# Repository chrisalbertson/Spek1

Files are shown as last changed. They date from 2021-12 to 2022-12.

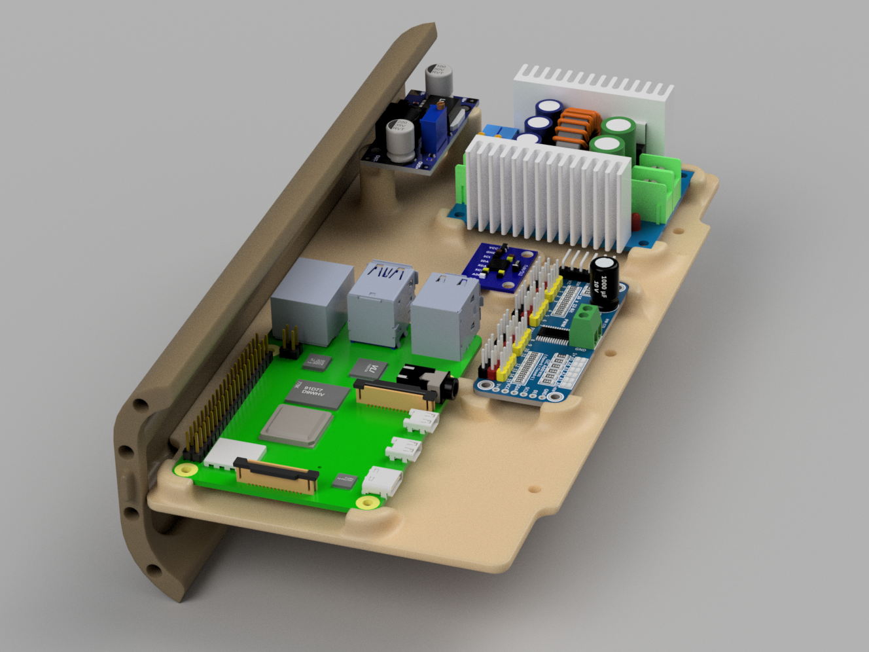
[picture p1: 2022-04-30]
Docs/trunk2 v34.png

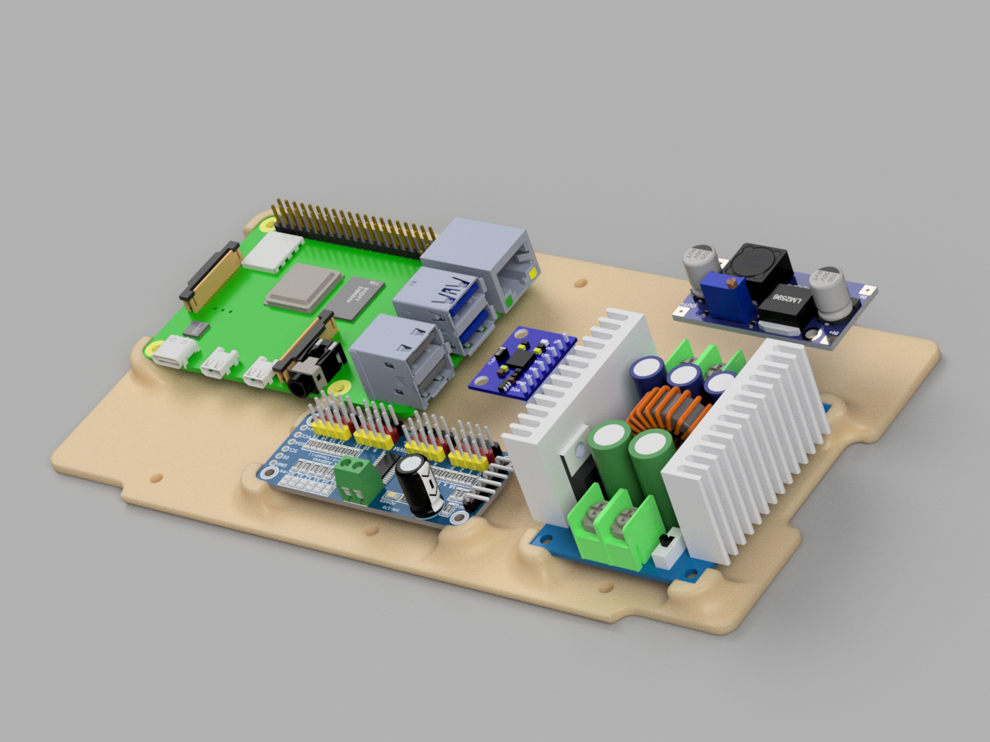
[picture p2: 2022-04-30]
Docs/trunk2 v30.png

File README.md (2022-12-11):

# Spek1

This repository holds my version of “Spot Micro” which was originated by Thingiverse user “KDY0523”. 

Why the name "Spek1"?  The work "Speck" means a small spot. and this robot is inspired by Boston Dynamic's "Spot", but this robot is much small.  It is a smaller Spot.    Then the leter "c" is removed.    The number "1" is added to imply that there coud be a series of these robots.

### Motivation

There are many Spot Micro projects on the Internet.  They are all derived from the same KDY0523 original.  I wanted a project that could incorporate some of the best ideas from other Spot Micro versions, plus some of my own ideas.  One of my main goals was to make a modifiable design.  I wanted modular and swapable parts.

The CAD files were all re-drawn, but retain the look and dimension of the original as much as possible. 

This Spot Micro uses a Raspberry Pi4 running Ubuntu Linux as the controller.  But the electronics are mounted to a tray and can be sapped out as a pre-wired unit, battery, power supplies, computer and all.

### How To Build

You can simply 3D print all the STL files and install the software on the Pi4 and you will in theory have a copy of my latest version.  Detailed instructions for doing this are in other documents in this repository.

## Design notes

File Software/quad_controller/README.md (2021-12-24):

# Quad Controller
This is what runs on the computer that is inside the robot.  

The target environment is a Raspberry Pi4 rning Ubuntu Linux.  But this
software is developed on a desktop Linux PC and runs there too in "simulation
mode" where the data that would have been sent to robot hardware is written 
to a log file.

At present this software does not do much.  I am using just one leg mounted
to a workbench to suport development.     It is still very early in the 
development process.

The goal is that the robot will move under remote control but make many of 
the decisions about hove to walk and balance by itself.   The remote
control will be either web based or via a remote X11 screen of by a
gamepad controller.

To run this type "python3 main.py"  then look at
http://localhost:2222 for a simply window.  Click on some controls and see
if anything happens.

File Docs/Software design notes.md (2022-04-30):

# Leg Motion Generator
## Inputs
* Velocity
	* angle relative to "front"
	* stride length (meters)
	* stride period (seconds)
* body pose
	* height
	* roll, pitch and yaw
* Stride Phase (normalized time)
* Preferred gait (amble, trot, ...)
## Outputs
* foot position in (x, y, z)
* foot velocity in (x', y', z')

## Implementation
### Startup
* initialize Leg object for each leg (call constructor function)
	* phase set to 0.0 (the neutral position)
* initialize body object (call constructor function)
	* set to "flat" and normal height above ground
* Start servo loop (run at maybe 20 Hz or faster)
	* find the foot contact plygon. This could be a point, line, triangle or quadrilateral
	* translate body so that center of gravity (accountng for direction gravity vector) is inside the foot-contact polygon
	* rotate body angles as much as possible to desired pose.
	* Adjust stance width or length if required to meet current stability goal.

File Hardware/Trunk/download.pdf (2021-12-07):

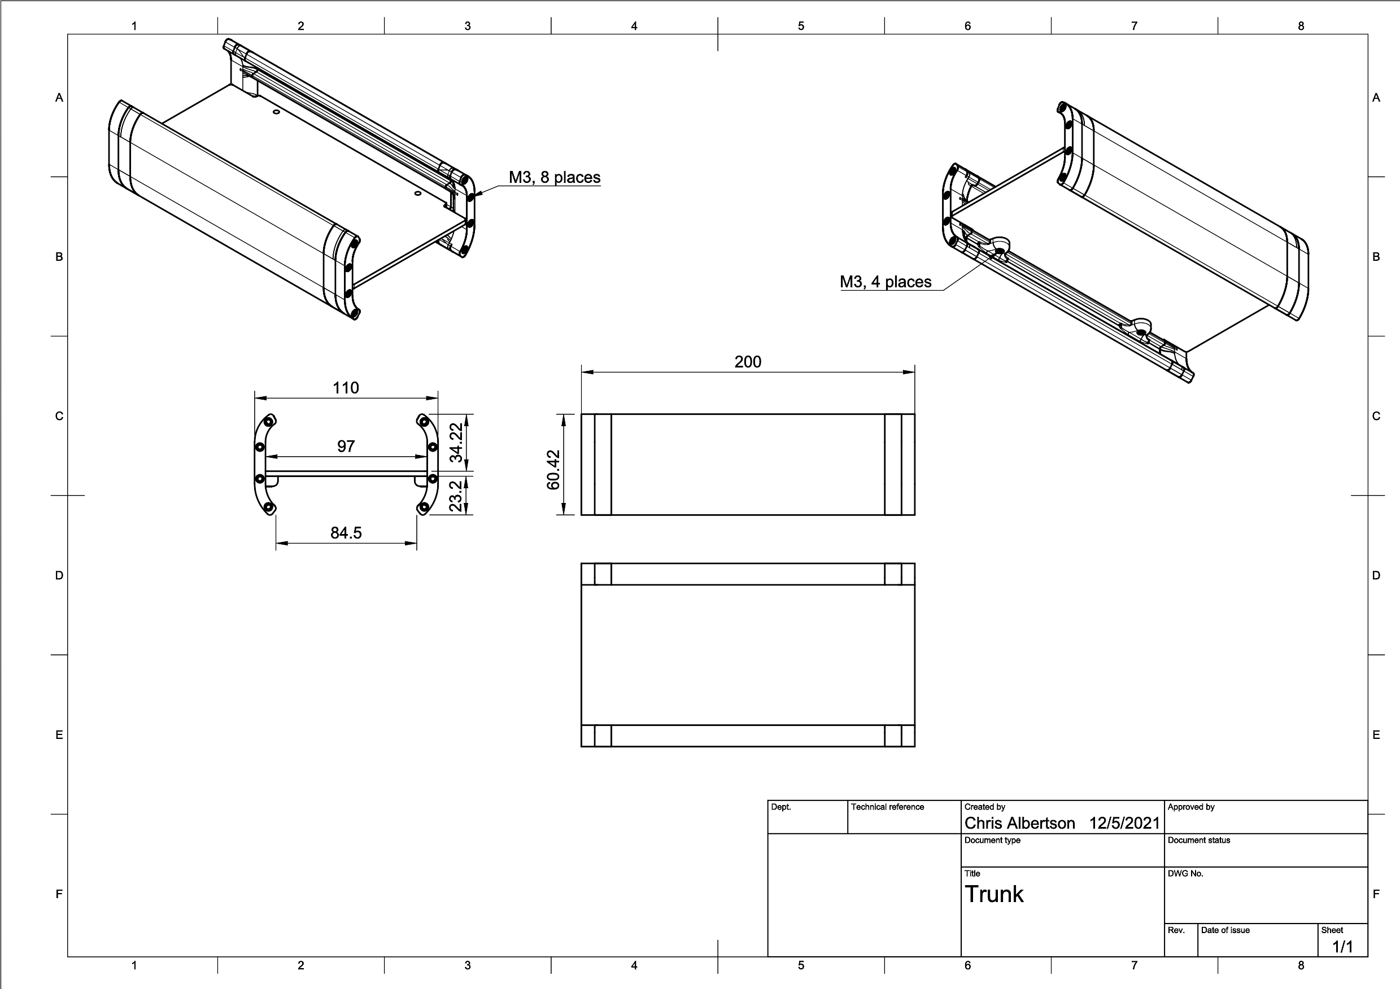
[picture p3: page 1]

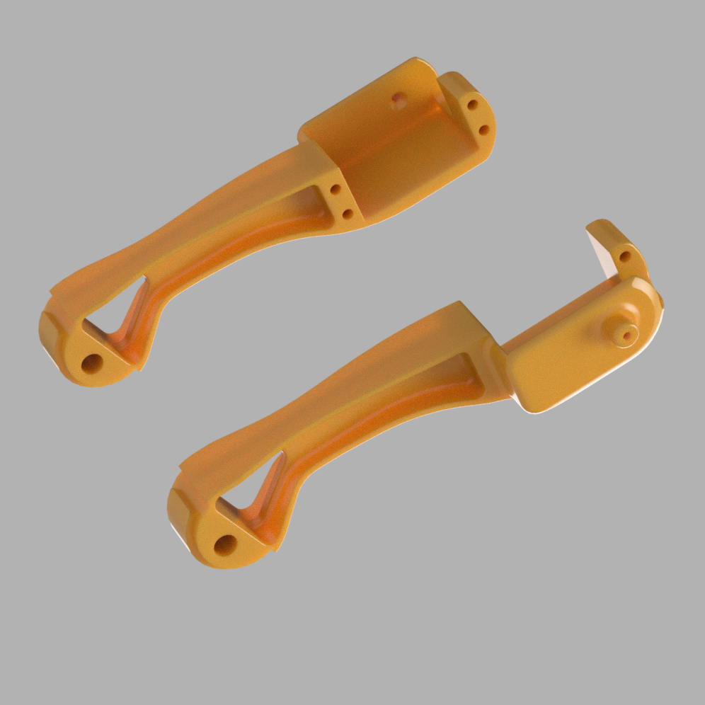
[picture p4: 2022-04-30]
Hardware/Legs/Spot MM1 Leg v29.png

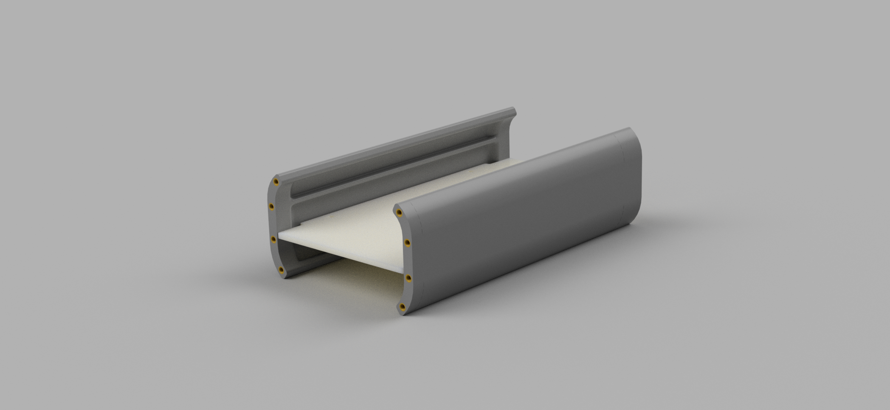
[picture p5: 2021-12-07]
Hardware/Trunk/Trunk v34.png

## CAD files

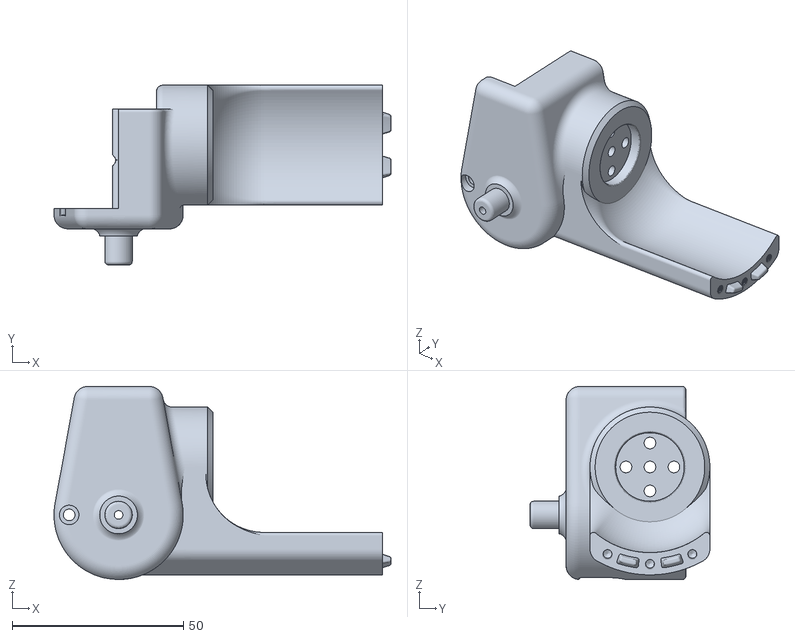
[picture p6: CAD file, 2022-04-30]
Hardware/Shoulder/ShoulderBlockMain.stl
98.4 x 52.5 x 56.4

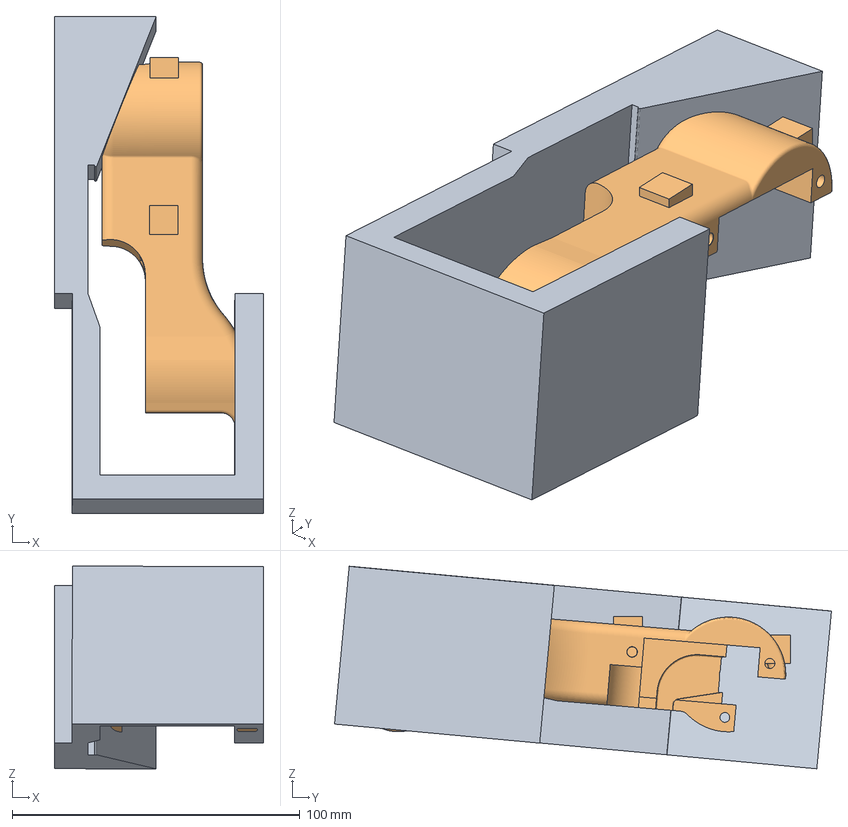
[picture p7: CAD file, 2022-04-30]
Hardware/Legs/upper_leg_mk2/AA6_upper_leg_main.3mf
72.7 x 172.6 x 70.4 mm
Print_Tool.stl
upper_leg_main.stl

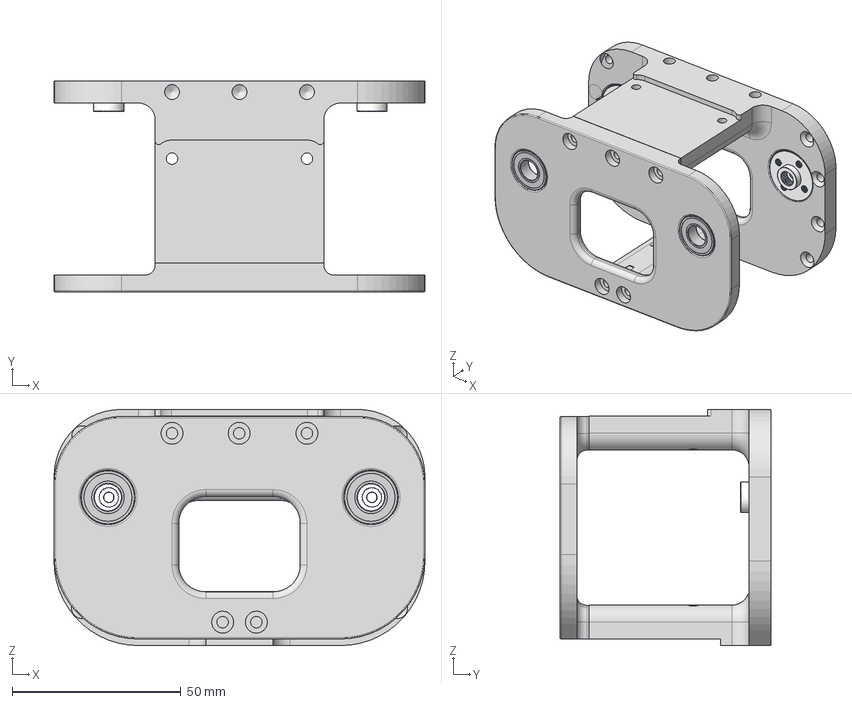
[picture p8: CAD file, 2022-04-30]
Hardware/Shoulder/Spot MM1 Shoulder Assembly v46.step
110.0 x 62.5 x 70.0 mm
Inner_Plate
Outer_Plate
_F688AZZ Outer Ring
_F688AZZ Inner Ring
_F688AZZ Shield1
_F688AZZ Ball x 12
_F688AZZ Shield2
_F688AZZ Outer Ring (1)
_F688AZZ Inner Ring (1)
_F688AZZ Shield1 (1)
_F688AZZ Ball (1) x 12
_F688AZZ Shield2 (1)

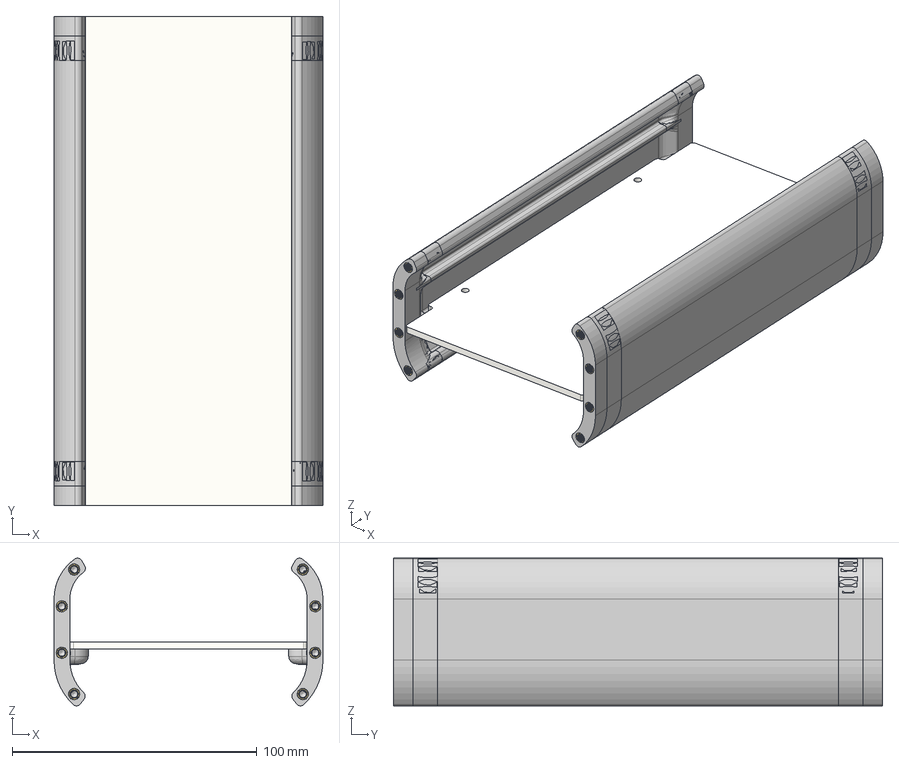
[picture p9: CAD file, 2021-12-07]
Hardware/Trunk/Trunk Assembly.step
110.0 x 200.0 x 60.4 mm
side plate, plastic only, LR x 2
F1-B-M3-Heatfit v1 (1) x 20
Tray

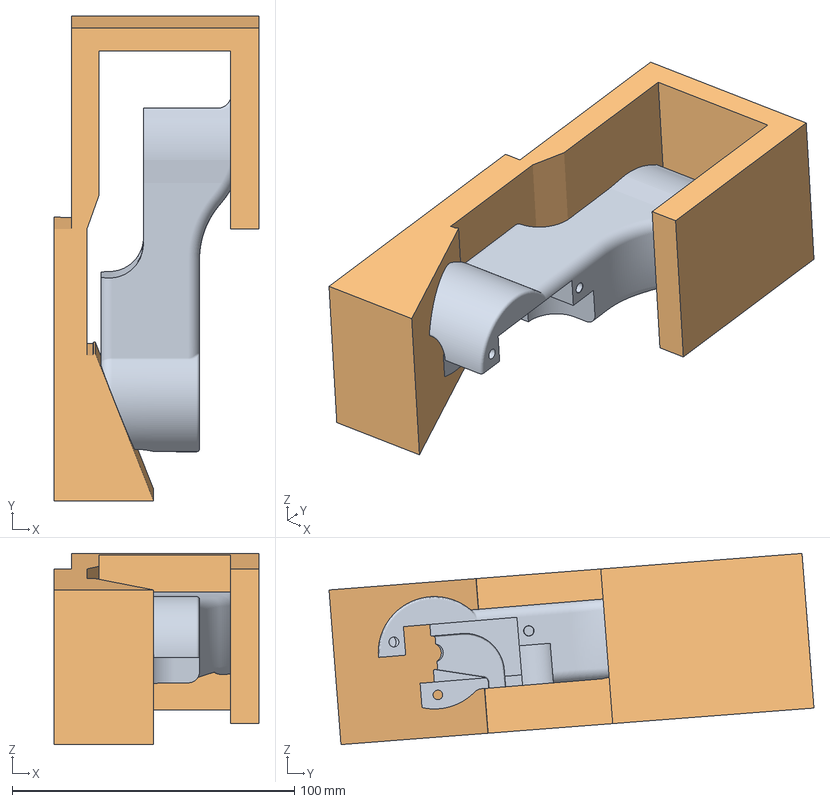
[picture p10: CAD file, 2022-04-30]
Hardware/Legs/upper_leg_mk2/AA6_upper_leg_main(Mirror).3mf
72.7 x 172.0 x 67.8 mm
upper_leg_main(Mirror).stl
Print_Tool.stl

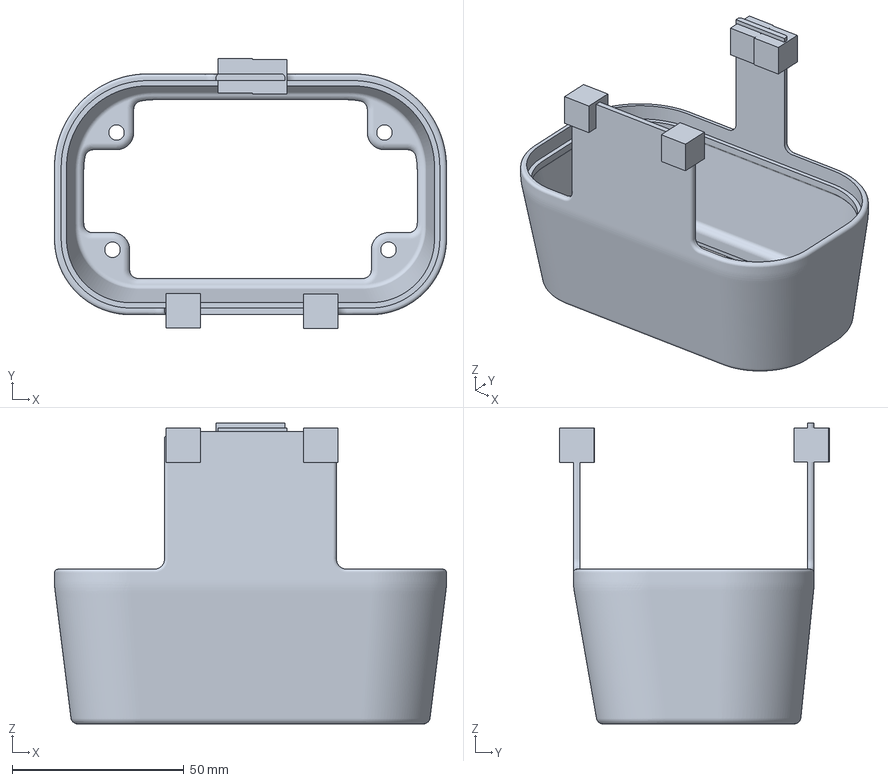
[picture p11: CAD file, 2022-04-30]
Hardware/covers/AA6_cover_tail.3mf
114.0 x 78.5 x 87.5 mm

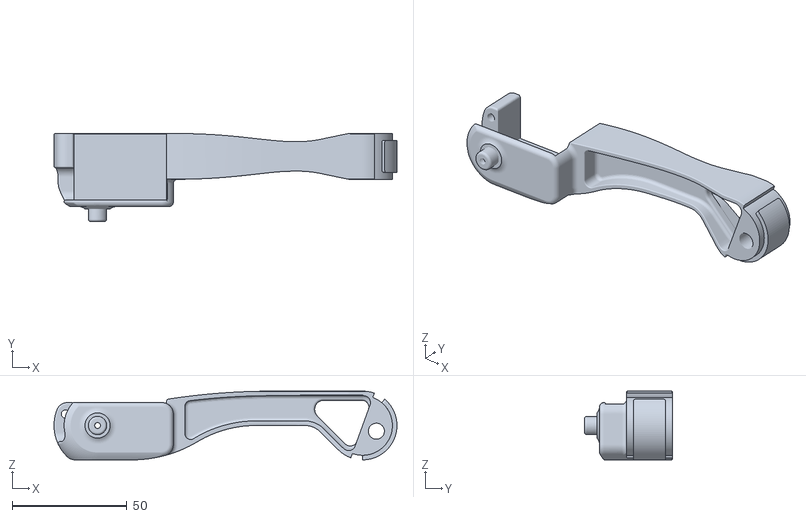
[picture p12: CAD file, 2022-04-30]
Hardware/Legs/LowerLeg_Mirror.stl
149.6 x 38.4 x 30.0

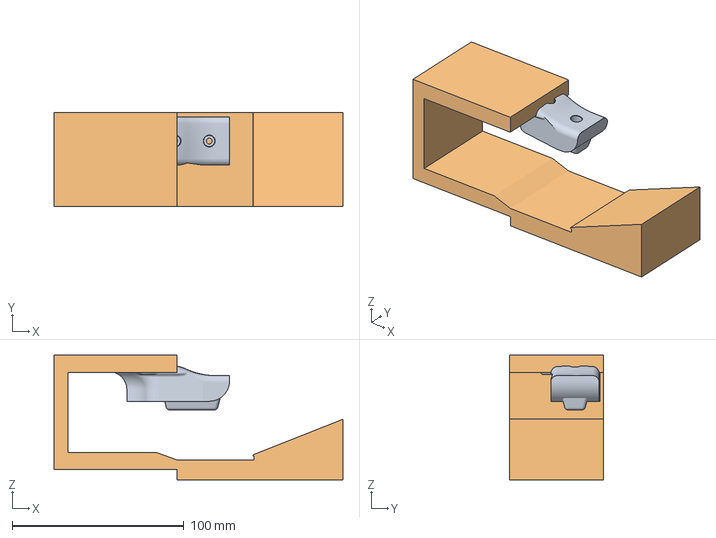
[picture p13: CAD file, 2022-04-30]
Hardware/Legs/upper_leg_mk2/AA6_upper_leg_bearing_cover(Mirror).3mf
168.2 x 55.0 x 72.6 mm
upper_leg_bearing_cover(Mirror).stl
Print_Tool.stl

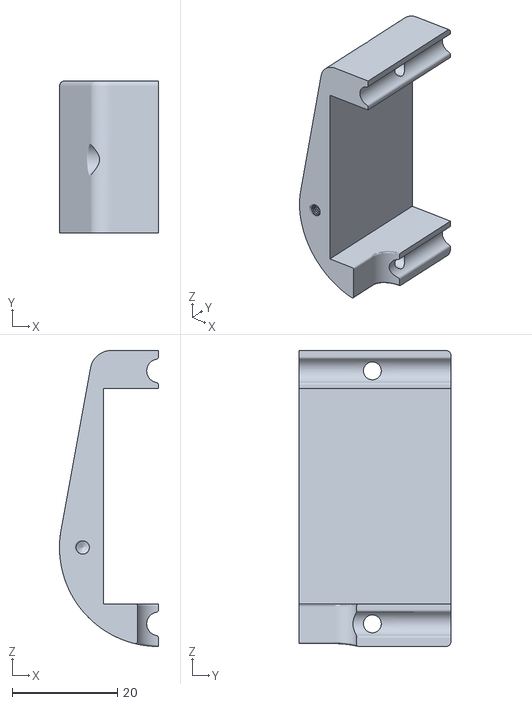
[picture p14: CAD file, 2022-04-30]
Hardware/Shoulder/ShoulderServoCover.stl
18.9 x 29.0 x 56.4

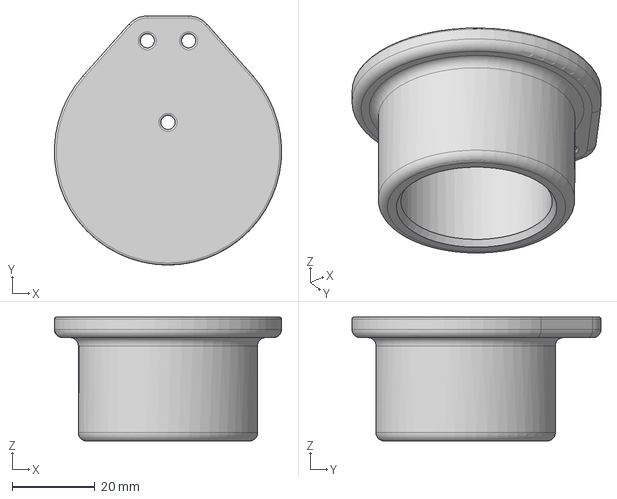
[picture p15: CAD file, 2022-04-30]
Hardware/tools/pipe_fitting.step
55.0 x 60.3 x 30.0 mm

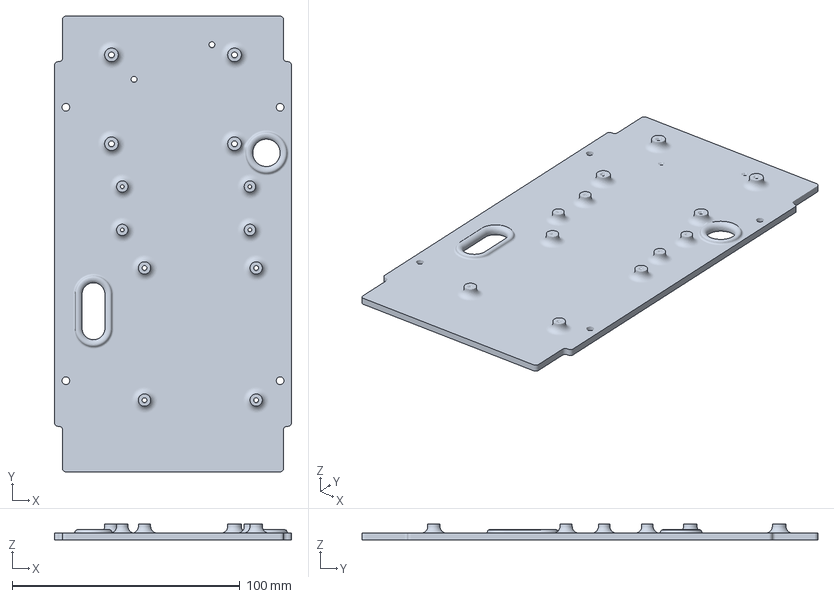
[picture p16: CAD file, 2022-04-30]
Hardware/Trunk/AA6_Left_Wrist.3mf
104.0 x 200.0 x 7.00 mm

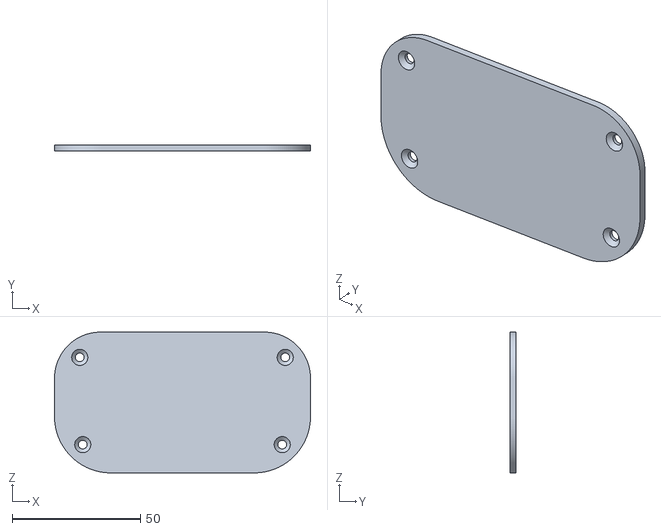
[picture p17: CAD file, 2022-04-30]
Hardware/covers/panel.stl
100.0 x 2.50 x 55.0

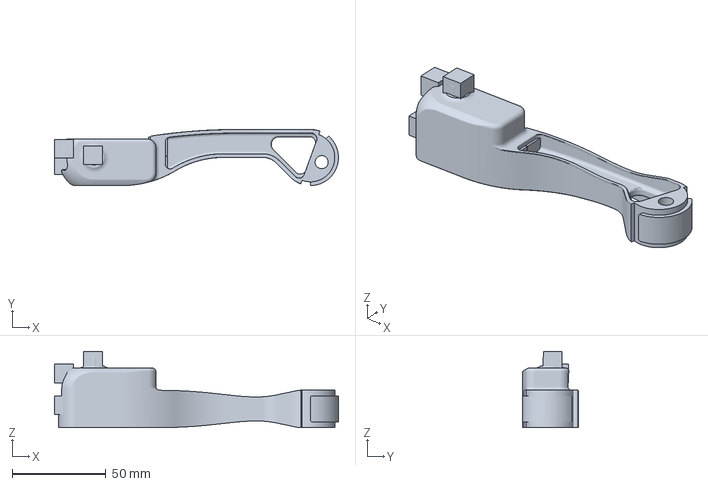
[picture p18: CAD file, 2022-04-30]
Hardware/Legs/AA6_LowerLeg_Mirror.3mf
151.7 x 30.0 x 40.8 mm

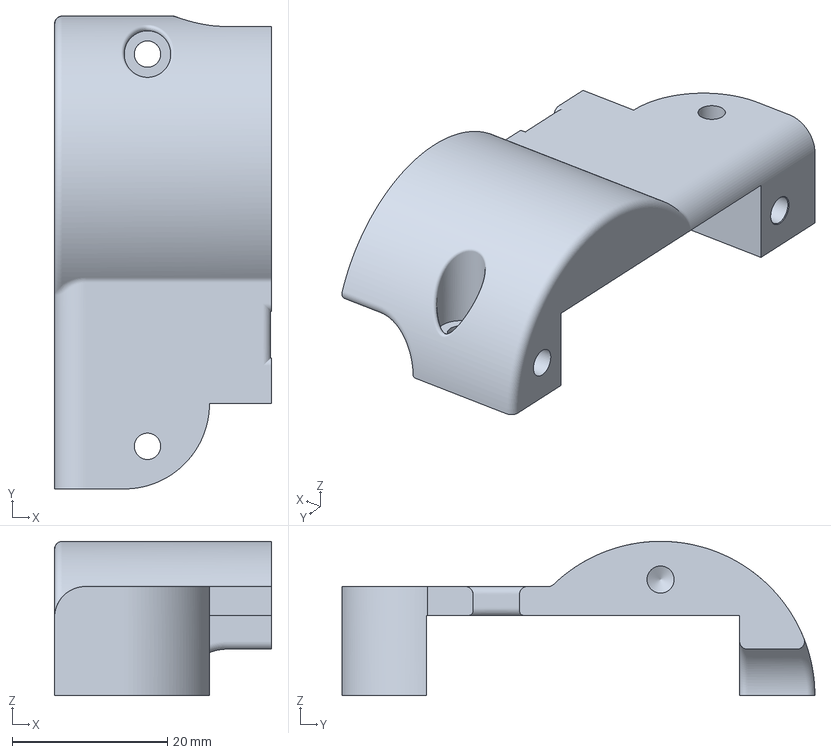
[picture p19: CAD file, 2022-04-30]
Hardware/Legs/upper_leg_mk2/AA6_upper_leg_servo_cover.3mf
28.0 x 61.0 x 19.9 mm

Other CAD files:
Hardware/Shoulder/ShoulderBearingHolder.stl
Hardware/tools/Bearing.stl
Hardware/Trunk/test_pannel (1).stl
Hardware/covers/AA6_panel.3mf
Hardware/Legs/Left_MidLimb.f3d
Hardware/Legs/Left_MidLimb.step
Hardware/Legs/Left_MidLimb_Cover.f3d
Hardware/Legs/Left_MidLimb_Cover.step
Hardware/Legs/Left_MidLimb_Cover.stl
Hardware/Legs/Left_Wrist.step
Hardware/Legs/foot.stl
Hardware/Legs/upper_leg_mk2/AA6_upper_leg_bearing_cover.3mf
Hardware/Legs/upper_leg_mk2/AA6_upper_leg_servo_cover(Mirror).3mf
Hardware/Legs/upper_leg_mk2/Print_Tool.stl
Hardware/Legs/upper_leg_mk2/upper leg v12.step
Hardware/Legs/upper_leg_mk2/upper leg v13.step
Hardware/Legs/upper_leg_mk2/upper leg v7.step
Hardware/Legs/upper_leg_mk2/upper_leg_bearing_cover(Mirror).stl
Hardware/Legs/upper_leg_mk2/upper_leg_bearing_cover.stl
Hardware/Legs/upper_leg_mk2/upper_leg_servo_cover(Mirror).stl
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

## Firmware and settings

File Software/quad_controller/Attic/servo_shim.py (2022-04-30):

import math

import logging
log = logging.getLogger(__name__)

import config

if config.UsePCA9685Hardware:
    from adafruit_servokit import ServoKit


class servo_shim:
    """Class to add a thin layer over the physical servo motors.

    The layer adds some features
    1) the servos might be not used at all. This allows testing on computers
       that don't have the hardware to drive servoes
    2) a calibration can be done to make the servos be more linera
    3) logging of commands for post analysis
    4) realtime performance capture
    5) enforment of limits

    This is intened to be a light weight class where all real-time funtions 
    have very low latency
    """

    def __init__(self, have_hardware: bool = False):
        """Class constructor, builds calibration and limits tables for quick lookup

        Parameters:
            have_hardware:  overides config if set True, used for unit tests
                            when it is hard to change config.  Should not be
                            set outside a test environment.

        """

        # limits set by the robot's mechanical structure.  These angles
        # are "theta" in radians and are relative to the joints
        # FIXME - using dummy values now.
        r_min = -2 * math.pi
        r_max =  2 * math.pi
        self.joint_limit = (
            # Joint1,           Joint2,           Joint3,         unused
            (r_min, r_max), (r_min, r_max), (r_min, r_max), (0, 0), # Front Left
            (r_min, r_max), (r_min, r_max), (r_min, r_max), (0, 0),  # Front Right
            (r_min, r_max), (r_min, r_max), (r_min, r_max), (0, 0),  # Rear Left
            (r_min, r_max), (r_min, r_max), (r_min, r_max), (0, 0))  # Rear Right


        """
        How to Install a Servo
        Use a servo tester of software to set the servo to the 50% point or 1 millisecond
        pulse width point.  Is is the mid point of the servo's range of motion.
        Then place the robot joint at the center point of it's range of motion and install
        the servo into the joint.   Try to get as close as possible but it is 
        nearly impossible
        to perfectly align the tow midpoints.   The spline has 25 teeth so at best you
        can only get to the closest tooth.
        
        After the servo is installed, command it again to it's mid point.  Note the 
        resulting angle of the joint.  This is the number that goes in this table below.
        
        So for example, if joint moves from 100 to 250 degrees it's mid point will be 
        175 degrees.   After you install the servo you notice that the joint movs to 177
        when you command the servo it's midrange point.   You enter 177 in the table below
        so as to record the INSTALLED joint angle at the servo mid point.
        
        Note enter the values in degrees.  We do this because it is a measured value
        ad I don't have a protractor marked in radians.   So the software does the conversion
        for us, later in this init function.
        """
        self.servo_installed_angle = (
            #   Joint1, Joint2, Joint3, unused
                0.0,    0.0,    0.0,    0.0,    # Front Left
                0.0,    0.0,    0.0,    0.0,    # Front Right
              -10.0,    0.0,   90.0,    0.0,    # Rear Left
                0.0,    0.0,    0.0,    0.0)    # Rear Right

       
        # A servo's effective direction is determined by how it is installed,
        # if the output spline shaft is facing forward or to the rear, left or right
        # If increasing servo degrees causes increased theta direction = +1
        # If increasing servo degrees causes decreased theta direction = -1
        # If the servo is not installed set the direction to zero.
        self.servo_installed_direction = (
            #   Joint1, Joint2, Joint3, unused
                -1,      1,      1,     0,    # Front Left
                 1,     -1,     -1,     0,    # Front Right
                -1,     -1,     -1,     0,    # Rear Left
                 1,      1,      1,     0)    # Rear Right

        """
        This table records the measured limits for each servo.  They are all
        different, and should be measured before they are installed.  The table
        is a list of tuples tuples with these feilds:
        (minimum microseconds, maximum microseconds, degrees of movement)
        """
        self.servo_range = (
            # Front Left
            (500, 2500, 180.0),     # Shoulder
            (500, 2500, 180.0),     # upper
            (500, 2500, 180.0),     # lower
            (1,2,3),                # not used

            # Front Right
            (500, 2500, 180.0),     # Shoulder
            (500, 2500, 180.0),     # upper
            (500, 2500, 180.0),     # lower
            (1,2,3),                # not used

            # Rear Left
            (500, 2500, 180.0),     # Shoulder
            (500, 2500, 180.0),     # upper
            (500, 2500, 180.0),     # lower
            (1,2,3),                # not used

            # Rear Right
            (500, 2500, 180.0),     # Shoulder
            (500, 2500, 180.0),     # upper
            (500, 2500, 180.0),     # lower
            (1,2,3),                # not used
        )

	# Set this depending on the servo specs.   Cheap servos use 50Hz
	# better servos ue 300+ Hz
        pwm_freq = 50

        if config.UsePCA9685Hardware or have_hardware:
            self.kit = ServoKit(channels=16, frequency=pwm_freq)
            for chan in range(16):
                self.kit.servo[chan].set_pulse_width_range(
                    min_pulse=self.servo_range[chan][0],
                    max_pulse=self.servo_range[chan][1])
                self.kit.servo[chan].actuation_range = self.servo_range[chan][2]

        """
        Below we do some pre-computation so as to save a tiny amount of processing later
        when running real-time.
        The relationship between radians on the robot frame and degrees in the servo frame
        is linear so we find the two constants "m" and "b" for a linear equation of
        the form "y = mx + b".
        """
        deg_per_radian = 180.0 / math.pi
        t2s = []    #set to empty list
        for chan in range(16):

            mid  = self.servo_range[chan][2]/2.0
            inst = self.servo_installed_angle[chan]
            direction = self.servo_installed_direction[chan]

            if direction == +1:
                mult = deg_per_radian
                bias = mid - inst
            elif direction == -1:
                mult = -deg_per_radian
                bias = mid + inst
            else:
                mult = 0
                bias = 0

            t2s.append((mult, bias))    # append a tuple

        # save it as a tuple, tuples are a little faster than lists.
        # and we need to do maybe 600 lookups per second
        self.theta2servo = tuple(t2s)

    def set_angle(self, channel_number: int, radians: float) -> None:
        """Set servo to specified joint angle

        Several things are done here
            1) radians converted to degrees
            2) the joint's mechanical limit is checked and will not be moved past this.
               The servo's range of motion limit is baked into the joint limit by the
               __init__() function, so we only have to check once here.
            3) check if real hardware is present either move the servo or write to a log.
        """

        # Keep joint angle within joint limits
        joint_min = self.joint_limit[channel_number][0]
        joint_max = self.joint_limit[channel_number][1]
        if not (joint_min <= radians <= joint_max):
            print('ERROR joint limit', channel_number, radians)
            radians = min(max(joint_min, radians), joint_max)

        m = self.theta2servo[channel_number][0]
        b = self.theta2servo[channel_number][1]
        servo_deg = ( m * radians + b)

        if config.UsePCA9685Hardware:
            print("SERVO", channel_number, servo_deg, "--", m, b)
            self.kit.servo[channel_number].angle = servo_deg
        else:
            pass
            # log.debug('angle ' + str(servo_deg) + ' chan ' + str(channel_number))
        return


    def set_raw_degrees(self, channel_number: int, degrees: float) -> None:
        """
        Args:
            channel_number: An integer in thranf 0...15 that i passed to servokit
            degrees:        The angle that the servo is to go to, passed
                            unchanged to the servo

        Returns:   None.


        This function should only be called during off-line calibration, not real-time,
        so it is OK to let it crash if the parameters are out of range
        """

        assert 0 =< channel_number =< 15
        assert 0.0 =< degrees =< 360.0
        
        self.kit.servo[channel_number].angle = degrees
        return


if __name__ == "__main__":

    logging.basicConfig(filename='quad_controller.log',
                        filemode='w',
                        level=logging.DEBUG, )
    servo = servo_shim(have_hardware=True)

    servo.set_angle(16, )

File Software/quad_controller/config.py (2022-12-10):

"""
This file holds only CONSTANTS

Our definition of "constant" is a value that does not change after execution begins.
so some code to get the constant values is allowed
"""

from enum import Enum


# Realtime control loop rate and heartbeat
rt_loop_freq = 20           # Hz
rt_heartbeat_period = 5     # Seconds




# This defines if the real robot hardware is present.
# If not the controller will not attempt to send data to or
# interact with physical device nor will it import the
# associated library modules.
UsePCA9685Hardware = True

body_number_of_legs = 4

# This the maximum forward speed the robot can walk.  Units are meters per second
max_forward_speed = 0.10

# on the Spot Micro, the second joint axis does NOT intersect the first but
# is vertically offset about 20 to 15 mm.    In many quadruped models the
#  J1 to J2 distance is just "l1" but SpotMicro needs FOUR constants
j1_to_j2_horizontal_offset = 0.060     # l1
j1_to_j2_vertical_offset   = 0.015     # l2
leg_upper_length           = 0.115     # l3
leg_lower_length           = 0.130     # l4


# This defines the "Wiring Diagram", that is which servo chanel is connected to which joint
# on which leg.  First we define some constants using enums
class leg_id (Enum):
    RF = 0
    LF = 1
    RR = 2
    LR = 3


class joint_id (Enum):
    THETA1 = 0          # shoulder, left/right
    THETA2 = 1          # shoulder, fore/aft
    THETA3 = 2          # knee


# Example: To get the servo chanel for the Right Front leg's knee joint use this:
# channel = servo_channel[leg_id.RF.value][joint_id.THETA3.value]
servo_channel_assignment = (( 0,  1,  2),
                           ( 4,  5,  6),
                           ( 8,  9, 10),
                           (12, 13, 14))

# This is the list of UIs (User Interfaces) that may be enabled.  Always at least one of these needs to
# be enabled
# NOTE:  The command line arguments processor should always ensure one of this is enabled.
ui_web_gui = False
ui_x11_gui = not ui_web_gui
ui_buttons = False       # set to True only if real hardware is present
ui_gamepad = False

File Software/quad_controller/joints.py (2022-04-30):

""" Module to handle moving the robot joint, either real or simulated.

This module assumes some conventions and a specific method of installation and calibration.

1)  The robot's zero point for each joint is when th shoulders are level and the legs are
pointing straight down.

2) To install a servo, first use a servo tester or software to command the servo
to it's mid-point.  This means to a 1500 uSec pulse length.

3) Find the mid-point of travel in the robot's joint.  Doing this by eye is good enough'

4) install the still centered servo so the joint is in its midrange of motion.  Each
spline groove on the servo is a few degree apart, so you can not get this perfect.
Get this as close as you can by eye.

5) the next step is to measure and calibrate so we can compensate for inevitable error
in the above process.  So use the test software to commend the joint to it's "zero
point" where the leg is straight.  Record the setting you had to use to "zero"
the joint.  This setting should be very close to the servo's mid-point.  Write it down.

6) command the servo to go to the lowest joint angle.   Note that this might require
a higher servo angle.  Servos can be installed to run "backward" or forward and
this depends on how the output shaft is facing relative to the robot.
So, run the servo until it either causes the robot's joint to het a stop and jam.
or until the servo motor has reach a limit.  Then back off a degree or two.
this is the lower limit of rotation.  Write this number down.

7) do the same in the other direction to find the upper imit of rotation.  It does
not matter why the limit is reach.  either the robot self-colides of the servo
runs out of range of motion.  Write this number down.

8) assemble all the servos using this method. then enter the data you collected
in the table below, that is three numbers for each servo.  (Eventually I will write
an automated tol to do this and we can store the numbers in a JSON file and
not have to write won number and edit ths Python file.)
"""

import math
import logging
log = logging.getLogger(__name__)
from typing import NamedTuple
import config

# The import will fail of there is no PCA9685 device on the I2C bus
# But this is expected if running on development PC in simulation mode
# config.UsePCA9685Hardware = True
try:
    from adafruit_servokit import ServoKit
    calibrated_frequency = 25000000. * 1.08
    print('define kit')
    kit = ServoKit(channels=16,
                   frequency=50,
                   reference_clock_speed=calibrated_frequency)
    pca9685 = True
except:
    # Set UsePCA9685Hardware flag, so we do not attempt to use adafruit_servokit
    pca9685 = False
    log.warning('failed to import adafruit_servokit')

if config.ui_web_gui:
    import PySimpleGUIWeb as sg
elif config.ui_x11_gui:
    import PySimpleGUI as sg


def have_pca9685():
    return pca9685


class ServoShim:
    """Class to add a thin layer over the physical servo motors.

    The layer adds some features
    1) the servos might be not used at all. This allows testing on computers
       that don't have the hardware to drive servos
    2) The joint angle is mapped to the servo angle
    3) logging of commands for post analysis
    4) realtime performance capture
    5) Joint and servo limits are enforced

    This is intended to be a light-weight class where all real-time functions
    have very low latency
    
    TBD:  Should think about driving the PCA9685 chip using uSec rather than
    letting Servo Kit convert degrees to uSec.   This way we can convert
    directly from radians to uSec and apply a per-servo calibration all at
    the same time.   See https://learn.adafruit.com/adafruit-16-channel-servo-driver-with-raspberry-pi/library-reference
    """

    def __init__(self):
        """Class constructor, builds calibration and limits tables for quick lookup

        Parameters:
            have_hardware:  overrides config if set True, used for unit tests
                            when it is hard to change config.  Should not be
                            set outside a test environment.
        """

        global kit

        # TABLE OF USER MEASURED VALUES
        #
        # the table below should be filled with data measured by the
        # method descried above.   The units are degrees in a
        # right-handed system.
        #
        # the table contains 16 tuples, 12 are used, four positions are not
        # used.  Each tuple contains the following, in degrees:
        # (zero_point, lower_limit, upper_limit) where
        #   zero_point -  when the servo is commanded to this value the leg is at
        #                 zero, which by convention is straight down and level
        #   direction  -  This is direction the servo rotates relative to Theta
        #                 Some servos are installed wit the output spline shaft
        #                 facing one way or the other.  Direction is set to
        #                 +1 if the servo rotation in the same direction as theta
        #                 and to -1 of the rotation is positive.   Direction is
        #                 set to servo if there is no servo installed on the channel.
        #   lower_limit - when the servo is commanded to this value the joint is
        #                 very near the point where it will physically stall out,
        #                 usually by the joint self-colliding because of mechanical limits
        #   upper_limit - As above but the joint is near the upper limit when the
        #                 servo is set to this value

        # The measurement is stored in a NamedTuple
        class SM(NamedTuple):
            zero_point:  float
            direction:   int
            lower_limit: float
            upper_limit: float

        no_servo = SM(0.0, 1, 0.0, 0.0)
        self.servo_measurements = (
            # Joint1,                  Joint2,                     Joint3,                    unused
            #                             100                         125.0
            # FIXME  -1 at J1 RIGHT is a HACK.   This needs to be fixed in IK.
            SM( 90.,  1, 70., 110.), SM( 92., -1, 10., 175.), SM(147., -1, 10., 250.), no_servo, # Front Left ( 0  1  2)
            SM( 96., -1, 76., 116.), SM( 90.,  1,  0., 170.), SM(135.,  1, 10., 250.), no_servo, # Front Right( 4  5  6)
            SM( 60., -1, 40.,  80.), SM(122., -1, 50., 180.), SM(180., -1, 30., 270.), no_servo, # Rear Left  ( 8  9 10)
            SM( 92.,  1, 80., 110.), SM( 90.,  1,  0., 180.), SM( 90.,  1,  0., 240.), no_servo) # Rear Right (12 13 14)
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

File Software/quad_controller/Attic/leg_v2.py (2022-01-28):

import math
import matplotlib.pyplot as plt

import logging
log = logging.getLogger(__name__)

from enum import Enum

import config

# We always count and order the legs this way, left to right and front to rear
class LegId (Enum):
    LF = 0      # Left Front is first and number 0
    RF = 1
    LR = 2
    RR = 3      # Right Rear is last and number 3


class Leg:

    def __init__(self, id: LegId):
        self.id = id
        self.l3 = config.leg_upper_length

        self.move_enabled = False
        self.sym_enabled = False

        self.last_th1 = 0
        self.last_th2 = 0
        self.last_th3 = 0

    def move_to_angles(self, angles):
        (th1, th2, th3) = angles

        if self.move_enabled:
            servo.setangle(chan_th1, th1)
            servo.setangle(chan_th2, th2)
            servo.setangle(chan_th3, th3)

        if sym_enabled:
            sym.setangle(chan_th1, th1)
            sym.setangle(chan_th2, th2)
            sym.setangle(chan_th3, th3)

        self.last_th1 = th1
        self.last_th1 = th1
        self.last_th1 = th1

    def enable_moves(self, allowed: bool=True):
        self.move_enabled = allowed

    def enable_sym(self, allowed: bool=True):
        self.sym_enabled = allowed


class Legs:

    def __init__(self):

        self.leg_list = []

        for leg_id in LegId:
            one_leg = Leg(LegId)
            self.leg_list.append(one_leg)
        return

    def move_to(self, foot_point_lf, foot_point_rf,
                      foot_point_lr, foot_point_rr):

        self.leg_list(LegId.LF).move_to(foot_point_lf)
        self.leg_list(LegId.LF).move_to(foot_point_rf)
        self.leg_list(LegId.LR).move_to(foot_point_lr)
        self.leg_list(LegId.RR).move_to(foot_point_rr)
        return

    def enable_moves(self, allowed: bool = True):
        for lg in self.leg_list:
            lg.enable_moves(allowed)
        return

    def enable_sys(self, allowed: bool = True):
        for lg in self.leg_list:
            lg.enable_sym(allowed)
        return

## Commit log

2021-12-09 Adding legs
    [Left_MidLimb.step, Left_MidLimb_Cover.step, Left_Wrist.step]
2021-12-10 first good upper/lower leg revision
    [Left_MidLimb.f3d, Left_MidLimb.step, Left_MidLimb_Cover.f3d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]
2021-12-10 changed shoulder to allow 6mm more space.
    [Inner Plate.f3d, Inner Plate.step, Inner_Plate.f3d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]
2021-12-24 making repository public
    [ShoulderBlockMain.stl]
2021-12-26 add 3d IK and joint limit checking
2021-12-30 Added "Mark II" upper leg CAD and STL files and also and XYZ test controller feature
    [AA6_upper_leg_bearing_cover.3mf, AA6_upper_leg_main.3mf, AA6_upper_leg_servo_cover.3mf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]
2022-01-04 servo cal and IK fixes
    [config.py, leg.py, servo_shim.py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]
2022-01-21 foot path throug the air using cubic splines
    [Inner_Plate.f3d, Inner_Plate.step, Outer_Plate.f3d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]
2022-01-28 legs cycle through x, y ,z
2022-01-31 re-wrote servo handling
2022-02-01 replace servo_shim.py with joints.py
    [joints.py, robot.py]
2022-02-18 reorganised and removed dead code
    [AA6_upper_leg_bearing_cover.3mf, AA6_upper_leg_main.3mf, AA6_upper_leg_servo_cover.3mf]
2022-04-30 Spot walks for first time
    [AA6_Left_Wrist.3mf, AA6_LowerLeg_Mirror.3mf, AA6_ShoulderBearingCover(Mirror).3mf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]
2022-12-15 new servo driver
